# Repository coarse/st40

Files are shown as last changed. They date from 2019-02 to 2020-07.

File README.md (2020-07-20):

# ST40 PCB
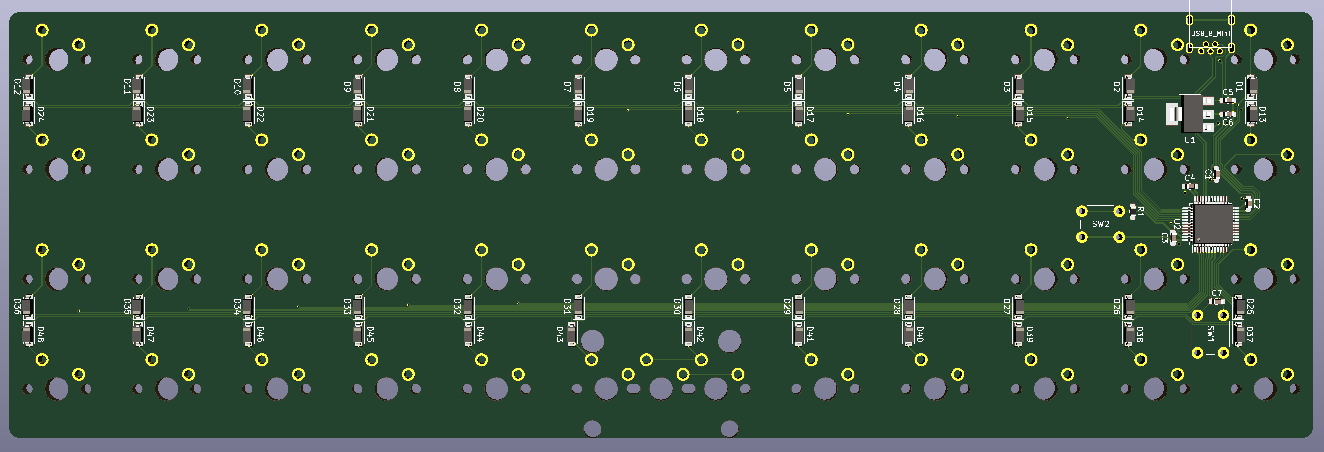
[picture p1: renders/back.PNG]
ST40 PCB

No frills, open source 40% ortholinear keyboard PCB

## Specs

- Planck-like layout
- South-facing LED (even though there is no backlight) because that's how switches were meant to be oriented
- No backlight, no underglow
- No fancy ESD protection
- No fancy reset circuit
- USB Mini because literally no frills
- STM32F072CBT6

## Requirements

- KiCad 5.0.1
- Default KiCad Schematic Library
- ai03's Switch Footprint Library (included as submodule)

## Notes

1. To be used as a reference for STM32F072CBT6 only
2. Can't guarantee that this PCB is compatible with Planck cases

## Questions?

 - Hit me up on Discord (Miyo#2210) or via e-mail (mfmayol@up.edu.ph)
 
## License

The design is licensed under [CC BY-SA 4.0](https://creativecommons.org/licenses/by-sa/4.0/).



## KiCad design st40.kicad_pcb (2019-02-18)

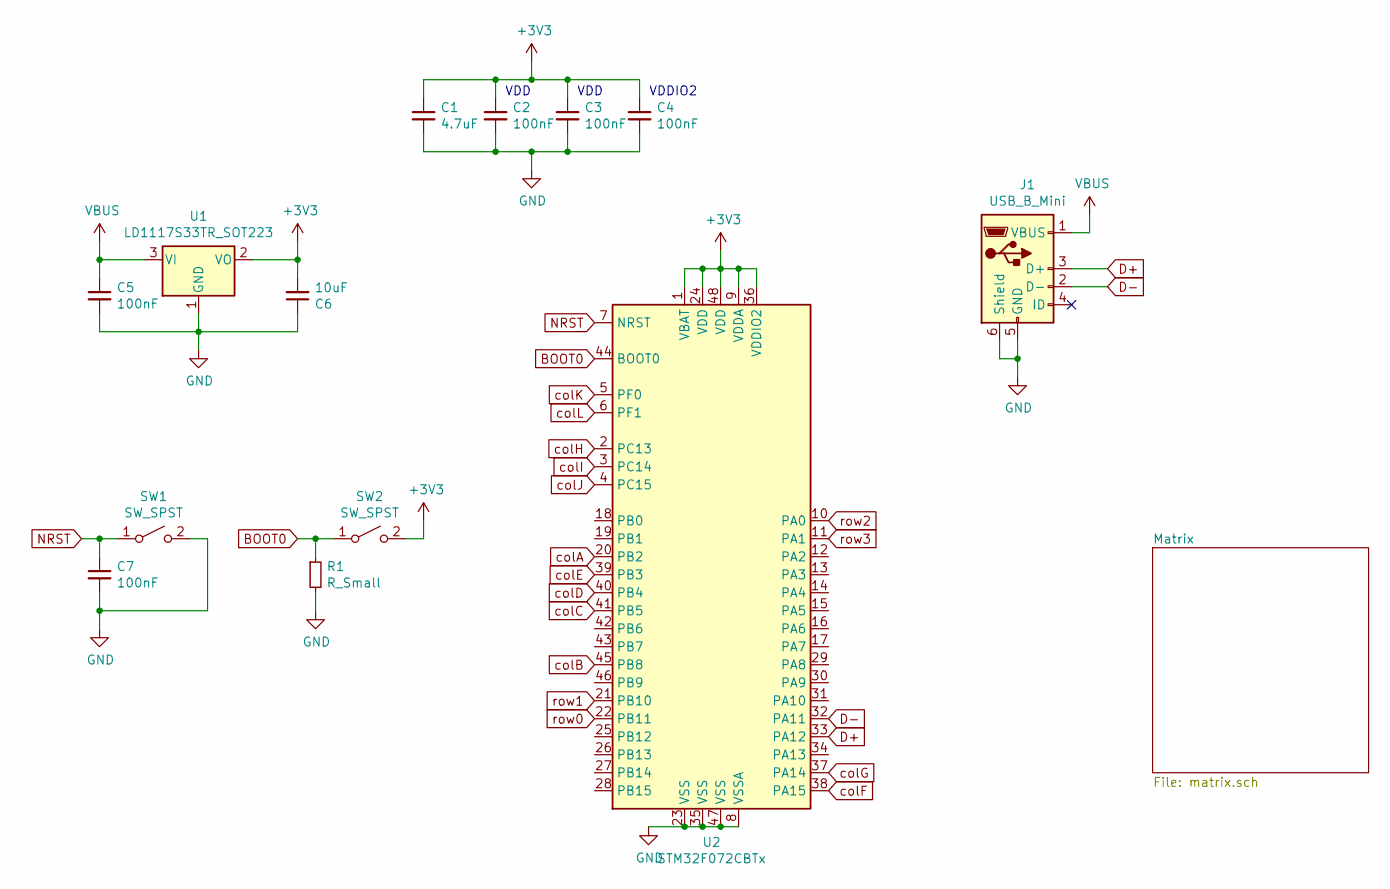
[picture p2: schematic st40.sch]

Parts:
C1: 4.7uF; C_0603_1608Metric_Pad1.05x0.95mm_HandSolder
C2, C3, C4, C5, C7: 100nF; C_0603_1608Metric_Pad1.05x0.95mm_HandSolder
C6: 10uF; C_0603_1608Metric_Pad1.05x0.95mm_HandSolder
J1: USB_B_Mini; USB-Mini-B_ LCSC-C46398
R1: R_Small; R_0603_1608Metric_Pad1.05x0.95mm_HandSolder
SW1, SW2: SW_SPST; SW_PUSH_6mm
U1: LD1117S33TR_SOT223; SOT-223
U2: STM32F072CBTx; LQFP-48_7x7mm_P0.5mm

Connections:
+3V3: C1.1, C2.1, C3.1, C4.1, C6.2, SW2.2 (B), U1.2 (VO), U2.1 (VBAT), U2.9 (VDDA), U2.24 (VDD), U2.36 (VDDIO2), U2.48 (VDD)
BOOT0: R1.1, SW2.1 (A), U2.44 (BOOT0)
D+: J1.3 (D+), U2.33 (PA12)
D-: J1.2 (D-), U2.32 (PA11)
GND: C1.2, C2.2, C3.2, C4.2, C5.2, C6.1, C7.2, J1.5 (GND), J1.6 (Shield), R1.2, SW1.2 (B), U1.1 (GND), U2.8 (VSSA), U2.23 (VSS), U2.35 (VSS), U2.47 (VSS)
NRST: C7.1, SW1.1 (A), U2.7 (NRST)
VBUS: C5.1, J1.1 (VBUS), U1.3 (VI)
colA: U2.20 (PB2); also elsewhere on the board
colB: U2.45 (PB8); also elsewhere on the board
colC: U2.41 (PB5); also elsewhere on the board
colD: U2.40 (PB4); also elsewhere on the board
colE: U2.39 (PB3); also elsewhere on the board
colF: U2.38 (PA15); also elsewhere on the board
colG: U2.37 (PA14); also elsewhere on the board
colH: U2.2 (PC13); also elsewhere on the board
colI: U2.3 (PC14); also elsewhere on the board
colJ: U2.4 (PC15); also elsewhere on the board
colK: U2.5 (PF0); also elsewhere on the board
colL: U2.6 (PF1); also elsewhere on the board
row0: U2.22 (PB11); also elsewhere on the board
row1: U2.21 (PB10); also elsewhere on the board
row2: U2.10 (PA0); also elsewhere on the board
row3: U2.11 (PA1); also elsewhere on the board

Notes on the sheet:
VDD
VDDIO2

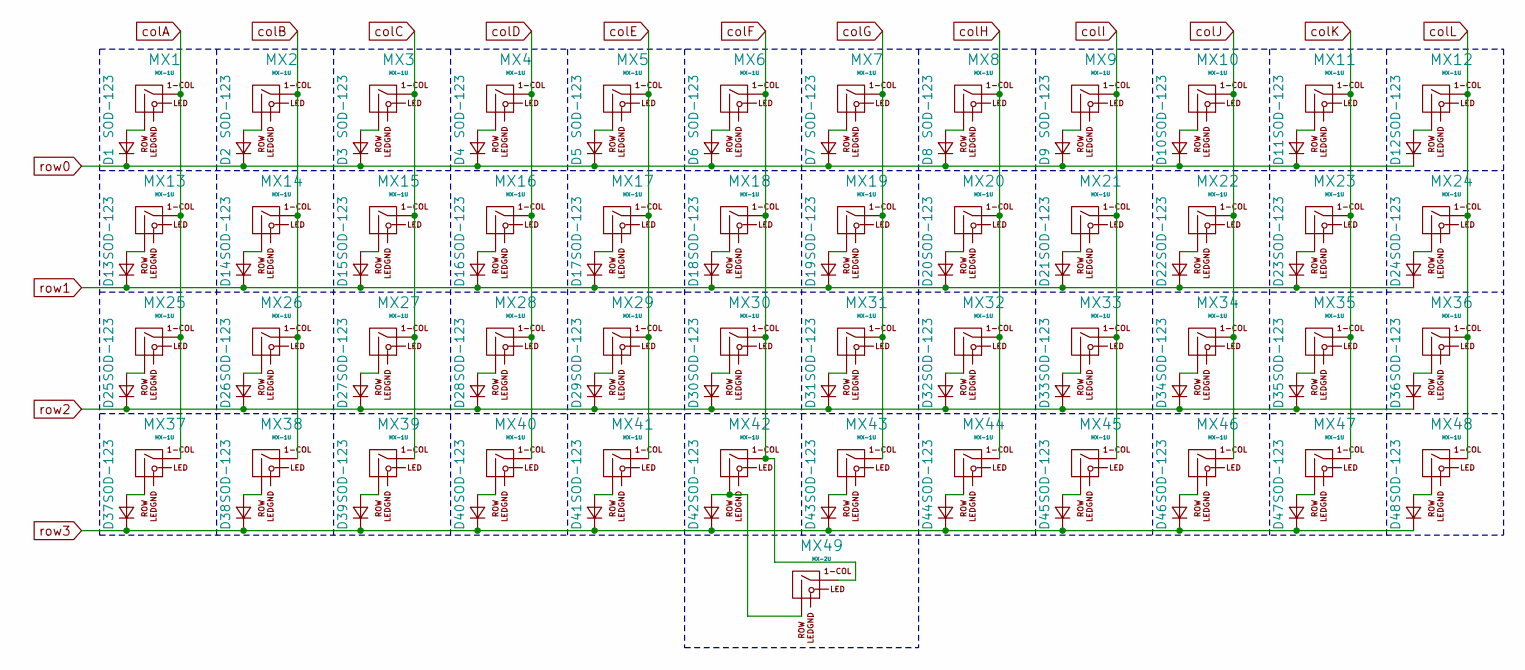
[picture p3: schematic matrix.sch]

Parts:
D1, D2, D3, D4, D5, D6, D7, D8, D9, D10, D11, D12, D13, D14, D15, D16, D17, D18, D19, D20, D21, D22, D23, D24, D25, D26, D27, D28, D29, D30, D31, D32, D33, D34, D35, D36, D37, D38, D39, D40, D41, D42, D43, D44, D45, D46, D47, D48: SOD-123; D_SOD-123
MX1, MX2, MX3, MX4, MX5, MX6, MX7, MX8, MX9, MX10, MX11, MX12, MX13, MX14, MX15, MX16, MX17, MX18, MX19, MX20, MX21, MX22, MX23, MX24, MX25, MX26, MX27, MX28, MX29, MX30, MX31, MX32, MX33, MX34, MX35, MX36, MX37, MX38, MX39, MX40, MX41, MX42, MX43, MX44, MX45, MX46, MX47, MX48: MX-1U; MXOnly-1U-NoLED
MX49: MX-2U; MXOnly-2U-ReversedStabilizers-NoLED

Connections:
unnamed: D1.2 (A), MX1.2 (ROW)
unnamed: D2.2 (A), MX2.2 (ROW)
unnamed: D3.2 (A), MX3.2 (ROW)
unnamed: D4.2 (A), MX4.2 (ROW)
unnamed: D5.2 (A), MX5.2 (ROW)
unnamed: D6.2 (A), MX6.2 (ROW)
unnamed: D7.2 (A), MX7.2 (ROW)
unnamed: D8.2 (A), MX8.2 (ROW)
unnamed: D9.2 (A), MX9.2 (ROW)
unnamed: D10.2 (A), MX10.2 (ROW)
unnamed: D11.2 (A), MX11.2 (ROW)
unnamed: D12.2 (A), MX12.2 (ROW)
unnamed: D13.2 (A), MX13.2 (ROW)
unnamed: D14.2 (A), MX14.2 (ROW)
unnamed: D15.2 (A), MX15.2 (ROW)
unnamed: D16.2 (A), MX16.2 (ROW)
unnamed: D17.2 (A), MX17.2 (ROW)
unnamed: D18.2 (A), MX18.2 (ROW)
unnamed: D19.2 (A), MX19.2 (ROW)
unnamed: D20.2 (A), MX20.2 (ROW)
unnamed: D21.2 (A), MX21.2 (ROW)
unnamed: D22.2 (A), MX22.2 (ROW)
unnamed: D23.2 (A), MX23.2 (ROW)
unnamed: D24.2 (A), MX24.2 (ROW)
unnamed: D25.2 (A), MX25.2 (ROW)
unnamed: D26.2 (A), MX26.2 (ROW)
unnamed: D27.2 (A), MX27.2 (ROW)
unnamed: D28.2 (A), MX28.2 (ROW)
unnamed: D29.2 (A), MX29.2 (ROW)
unnamed: D30.2 (A), MX30.2 (ROW)
unnamed: D31.2 (A), MX31.2 (ROW)
unnamed: D32.2 (A), MX32.2 (ROW)
unnamed: D33.2 (A), MX33.2 (ROW)
unnamed: D34.2 (A), MX34.2 (ROW)
unnamed: D35.2 (A), MX35.2 (ROW)
unnamed: D36.2 (A), MX36.2 (ROW)
unnamed: D37.2 (A), MX37.2 (ROW)
unnamed: D38.2 (A), MX38.2 (ROW)
unnamed: D39.2 (A), MX39.2 (ROW)
unnamed: D40.2 (A), MX40.2 (ROW)
unnamed: D41.2 (A), MX41.2 (ROW)
unnamed: D42.2 (A), MX42.2 (ROW), MX49.2 (ROW)
unnamed: D43.2 (A), MX43.2 (ROW)
unnamed: D44.2 (A), MX44.2 (ROW)
unnamed: D45.2 (A), MX45.2 (ROW)
unnamed: D46.2 (A), MX46.2 (ROW)
unnamed: D47.2 (A), MX47.2 (ROW)
unnamed: D48.2 (A), MX48.2 (ROW)
colA: MX1.1 (COL), MX13.1 (COL), MX25.1 (COL), MX37.1 (COL); also elsewhere on the board
colB: MX2.1 (COL), MX14.1 (COL), MX26.1 (COL), MX38.1 (COL); also elsewhere on the board
colC: MX3.1 (COL), MX15.1 (COL), MX27.1 (COL), MX39.1 (COL); also elsewhere on the board
colD: MX4.1 (COL), MX16.1 (COL), MX28.1 (COL), MX40.1 (COL); also elsewhere on the board
colE: MX5.1 (COL), MX17.1 (COL), MX29.1 (COL), MX41.1 (COL); also elsewhere on the board
colF: MX6.1 (COL), MX18.1 (COL), MX30.1 (COL), MX42.1 (COL), MX49.1 (COL); also elsewhere on the board
colG: MX7.1 (COL), MX19.1 (COL), MX31.1 (COL), MX43.1 (COL); also elsewhere on the board
colH: MX8.1 (COL), MX20.1 (COL), MX32.1 (COL), MX44.1 (COL); also elsewhere on the board
colI: MX9.1 (COL), MX21.1 (COL), MX33.1 (COL), MX45.1 (COL); also elsewhere on the board
colJ: MX10.1 (COL), MX22.1 (COL), MX34.1 (COL), MX46.1 (COL); also elsewhere on the board
colK: MX11.1 (COL), MX23.1 (COL), MX35.1 (COL), MX47.1 (COL); also elsewhere on the board
colL: MX12.1 (COL), MX24.1 (COL), MX36.1 (COL), MX48.1 (COL); also elsewhere on the board
row0: D1.1 (K), D2.1 (K), D3.1 (K), D4.1 (K), D5.1 (K), D6.1 (K), D7.1 (K), D8.1 (K), D9.1 (K), D10.1 (K), D11.1 (K), D12.1 (K); also elsewhere on the board
row1: D13.1 (K), D14.1 (K), D15.1 (K), D16.1 (K), D17.1 (K), D18.1 (K), D19.1 (K), D20.1 (K), D21.1 (K), D22.1 (K), D23.1 (K), D24.1 (K); also elsewhere on the board
row2: D25.1 (K), D26.1 (K), D27.1 (K), D28.1 (K), D29.1 (K), D30.1 (K), D31.1 (K), D32.1 (K), D33.1 (K), D34.1 (K), D35.1 (K), D36.1 (K); also elsewhere on the board
row3: D37.1 (K), D38.1 (K), D39.1 (K), D40.1 (K), D41.1 (K), D42.1 (K), D43.1 (K), D44.1 (K), D45.1 (K), D46.1 (K), D47.1 (K), D48.1 (K); also elsewhere on the board

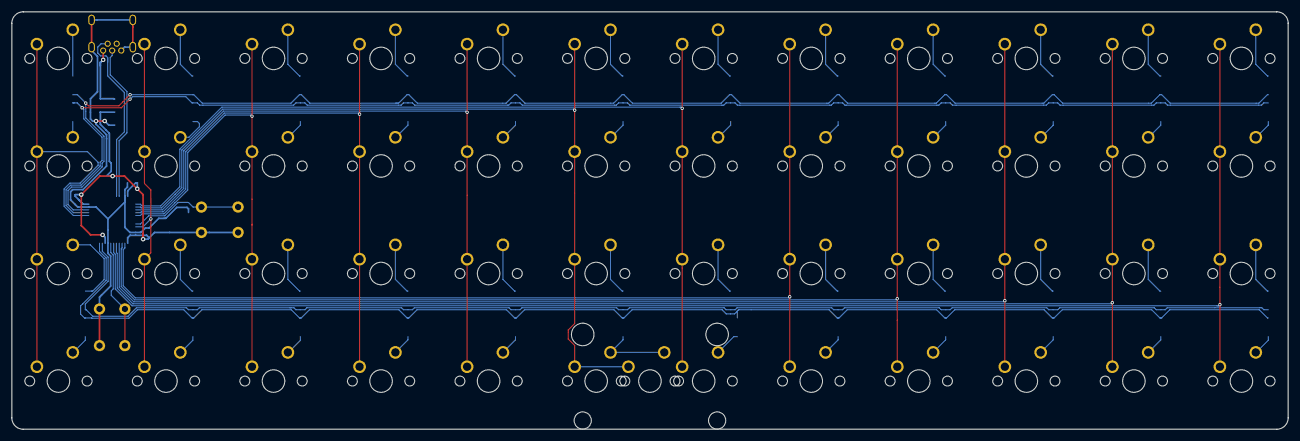
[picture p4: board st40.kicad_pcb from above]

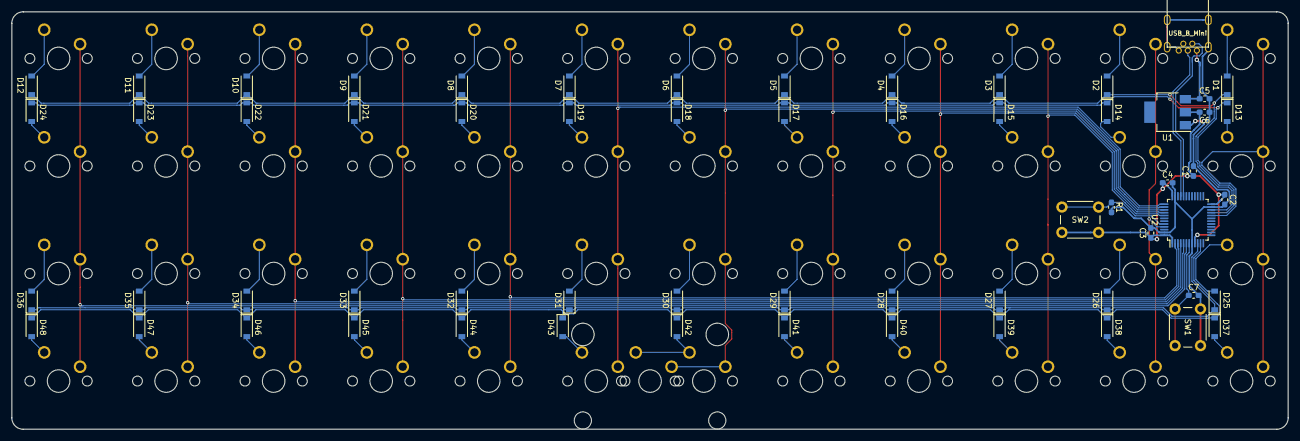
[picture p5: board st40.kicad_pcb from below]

Board: 2 copper layers, 226.1 x 73.9 mm, 110 parts (61 on the bottom side), 71 nets.

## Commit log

2019-02-18 initial and probably final commit
    [matrix.sch, st40.kicad_pcb, st40.sch]
2019-02-18 fixed missing traces from col/rows to mcu, did some rerouting, fixed board outline
    [matrix.sch, st40.kicad_pcb, st40.sch]
2019-02-18 moved diode placement
    [st40.kicad_pcb]
